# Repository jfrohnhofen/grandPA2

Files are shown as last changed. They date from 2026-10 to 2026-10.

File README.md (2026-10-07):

# grandPA2

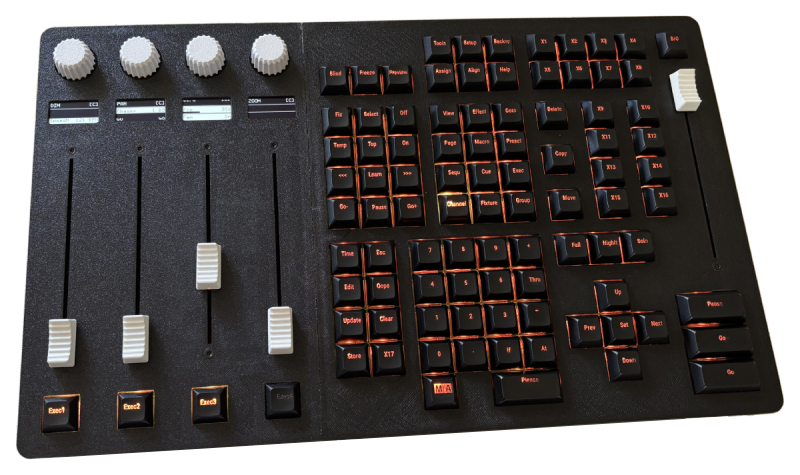
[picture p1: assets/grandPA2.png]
grandPA2 Hardware Controller


grandPA2 — the grandMA2 Physical Accessory — is a custom hardware controller inspired by the grandMA2 lighting console. It features a custom PCB, Rust-based STM32 firmware, and a companion Windows host application for grandMA2 WebRemote integration.

This is a private hobby project and is in no way affiliated with, endorsed by, or associated with MA Lighting Technology or the grandMA2 brand.

## Quick Start

To get the grandPA2 up and running, you need to build the firmware, configure your lighting software, and launch the host application:

1. **Flash Firmware:** Enter the firmware dev shell (`nix develop .#firmware`), build with `cargo build --release`, and flash to your Black Pill via `probe-rs` or `dfu-util`.
2. **Configure grandMA2 onPC:** Go to Global Settings and enable the **WebRemote**. Create a user account (default expected is username `grandPA2`, password `secret`).
3. **Launch Host App:** Enter the host dev shell (`nix develop .#host`), build with `cargo build --release --target x86_64-pc-windows-gnu`, and run the executable with your connection string: `grandPA2.exe grandPA2:secret@127.0.0.1:80`.

## Project Structure

- `firmware/` - Rust firmware for the STM32F4 (Black Pill) microcontroller.
- `host/` - Rust-based Windows companion application for screen scraping and two-way communication via grandMA2 WebRemote.
- `pcb/` - EasyEDA project and hardware design files.
- `keycaps/` - Python scripts to generate custom SVG legends for the keycaps.
- `casing/` - 3D models for the enclosure.

## Development Environment (Nix)

This project uses [Nix](https://nixos.org/) [Flakes](https://nixos.wiki/wiki/Flakes) to provide a reproducible development environment.

To enter the respective development environments with all necessary toolchains installed (Rust, cross-compilers, Python, Inkscape, etc.):

- **Firmware Dev Shell:** `nix develop .#firmware`
- **Windows Host App Dev Shell:** `nix develop .#host`
- **Keycap Generation Shell:** `nix develop .#keycaps`

---

## Hardware & PCB (`pcb/`)

The hardware is designed in EasyEDA. The `grandPA2.eprj` file can be imported into EasyEDA to view the schematics and PCB layout.

**Hardware Features:**
- STM32F411 (Black Pill) microcontroller
- 11x11 Switch Matrix (with 94 usable keys)
- 4x EC11 Rotary Encoders with push buttons
- 5x Analog Faders
- 4x OLED Displays (SH1106 via SPI)
- 94x WS2812 RGB LEDs

The button layout strictly follows the layout from a physical grandMA2 console, plus 16 extra buttons mapped as the X1 to X16 hardkeys. One fader acts as the Grand Master, while the other 4 faders are mapped as Executors 1-4. The buttons underneath the 4 faders are mapped as the main executor buttons for Executors 6-9.

The 4 rotary encoders are hardcoded to the following attributes:
- **Encoder 0:** Dimmer (Dim)
- **Encoder 1:** Position (Pan)
- **Encoder 2:** Position (Tilt)
- **Encoder 3:** Focus (Zoom)

The hardware is split into three separate boards for easier manufacturing and assembly:
1. **Main Board:** Hosts the Black Pill microcontroller and various IDC connectors to route signals.
2. **Matrix Board:** Contains the keyboard scanning matrix and the 94 RGB LEDs. It also contains a smaller sub-PCB for the executor buttons.
3. **Peripheral Boards:** Smaller boards, each used for connecting one display, one encoder, and one fader.

### MCU Pin Assignments
The Black Pill (STM32F411) uses the following pins for the various peripherals:

| Peripheral | Sub-component / Signal | Pin(s) |
| :--- | :--- | :--- |
| **Encoders** | Encoder 0 (A, B, Push) | `PA8`, `PA9`, `PC13` |
| | Encoder 1 (A, B, Push) | `PA15`, `PB3`, `PC14` |
| | Encoder 2 (A, B, Push) | `PB4`, `PB5`, `PB9` |
| | Encoder 3 (A, B, Push) | `PB6`, `PB7`, `PB8` |
| **Faders** | Faders 0 - 4 | `PA0`, `PA1`, `PA2`, `PA3`, `PA4` |
| **Matrix Scanner** | SCK, Row Latch, Row Data In | `PB13`, `PB12`, `PB14` |
| | Col Latch, Col Data Out | `PA10`, `PB15` |
| **Displays (SPI)** | SCK, MOSI, DC | `PA5`, `PA7`, `PC15` |
| | CS0, CS1, CS2, CS3 | `PB0`, `PB1`, `PB2`, `PB10` |
| **WS2812 LEDs** | Data Line | `PA6` |

### IDC Connector Pinouts (Main Board)
The main board routes signals to the peripherals via IDC connectors. The pinouts are as follows:

**Matrix (10-pin)**
| Odd Pin | Signal | Even Pin | Signal |
| :--- | :--- | :--- | :--- |
| **1** | `3V3` | **2** | `ROW_LATCH` |
| **3** | `SCK` | **4** | `ROW_DATA` |
| **5** | `COL_LATCH` | **6** | `COL_DATA` |
| **7** | `GND` | **8** | `GND` |
| **9** | `GND` | **10** | `GND` |

**Displays (10-pin)**
| Odd Pin | Signal | Even Pin | Signal |
| :--- | :--- | :--- | :--- |
| **1** | `CS` | **2** | `MOSI` |
| **3** | `3V3` | **4** | `DC` |
| **5** | `GND` | **6** | `RST` |
| **7** | `GND` | **8** | `SCK` |
| **9** | `GND` | **10** | `GND` |

**Encoders (6-pin)**
| Odd Pin | Signal | Even Pin | Signal |
| :--- | :--- | :--- | :--- |
| **1** | `ENC_A` | **2** | `ENC_BTN` |
| **3** | `ENC_B` | **4** | `GND` |
| **5** | `GND` | **6** | `GND` |

**Faders (6-pin)**
| Odd Pin | Signal | Even Pin | Signal |
| :--- | :--- | :--- | :--- |
| **1** | `3V3` | **2** | `FADER` |
| **3** | `GND` | **4** | `GND` |
| **5** | `GND` | **6** | `GND` |

**LEDs (6-pin)**
| Odd Pin | Signal | Even Pin | Signal |
| :--- | :--- | :--- | :--- |
| **1** | `5V` | **2** | `5V` |
| **3** | `LED_DATA` | **4** | `GND` |
| **5** | `GND` | **6** | `GND` |

### Bill of Materials (BOM)
In addition to the components listed in the PCB design, the following components are required:
- 1x STM32F411 Black Pill board
- 94x MX button switches
- 90x 1U keycaps
- 4x 2U keycaps
- 4x EC11 rotary encoders
- 5x linear faders (128mm travel, e.g., 10k linear)
- Various 6P, 10P, and 16P IDC sockets, connectors, and ribbon cables for inter-board connections.
- M3 8mm screws (for the casing).
- Self-cutting screws (for mounting the PCB).

### Keycaps & Legends (`keycaps/`)
Custom keycaps are required to mimic the lighting console layout. The `generate.py` script generates perfectly aligned, spaced SVGs for standard 1U and 2U keys, complete with a custom font and logos.
- To generate: `nix develop .#keycaps`, then `python generate.py`.
- The script uses Inkscape via the CLI to automatically convert the text elements into SVG paths, ensuring they render correctly for printing or laser engraving.

*Tip: For the best results, use transparent keycaps sprayed with matte black paint, and then laser-ablate the labels.*

### Casing (`casing/`)
The 3D printed casing for grandPA2 is designed in Onshape. You can view, copy, and export the CAD models from the following link:
[grandPA2 Casing on Onshape](https://cad.onshape.com/documents/a69522914b9fd6c3a378e748/w/ff3ce6cc18ab1158cfabc037/e/642326b3695c8e1d442461fe)
Exported STEP files are also in the repository. There is a "split" version that fits into the 256mm³ print volume of a Bambu Lab P1S printer.

---

## Firmware (`firmware/`)

The firmware is written in Rust for the STM32F411 (Black Pill) microcontroller. It acts as a USB MIDI Audio Class device.

### Protocol Details
The firmware and the host software communicate via standard USB MIDI, mixed with custom SysEx commands:

- **Hardware to Host (Standard MIDI):**
  - **Matrix Buttons:** Sent as MIDI Note On/Off messages (Notes 0–120) on Channel 1.
  - **Encoders:** The rotation is sent as Control Change (CC) messages (CC 0–3, relative 2's complement) on Channel 2. The encoder push buttons send Note On/Off messages (Notes 0–3) on Channel 2.
  - **Faders:** Sent as absolute Control Change (CC) messages (CC 0–4) on Channel 3.
  
- **Host to Hardware (Custom SysEx - ID 0x7D):**
  - **LED Updates (Command ID `0x10`):** Host sends 24-bit RGB colors for all 94 LEDs. The payload is 282 bytes (94 LEDs * 3 bytes for R, G, B). Each byte is 7-bit masked.
  - **OLED Displays (Command ID `0x20` to `0x2F`):** Host sends 1BPP pixel chunks. DisplayID is `(Cmd - 0x20) / 4` and ChunkID is `(Cmd - 0x20) % 4`. The payload is 7-bit packed and unpacked by the firmware into 256 bytes per chunk.

SysEx messages are wrapped in standard MIDI `0xF0` and `0xF7` bytes. The payload begins with the Custom Manufacturer ID `0x7D`, followed by the Command ID, and then the data payload bytes (which are strictly 7-bit compliant).

### Building and Flashing
1. Enter the firmware dev shell: `nix develop .#firmware`
2. Build the project: `cargo build --release`
3. Flash the firmware onto the Black Pill using `probe-rs` or `dfu-util`.

---

## Host Software (`host/`)

The host software is a Windows application written in Rust. It acts as the bridge between the grandPA2 hardware and the grandMA2 onPC software by combining screen scraping with WebRemote integration.

### grandMA2 WebRemote Integration

The host uses websockets to communicate with the grandMA2 WebRemote API. This handles bidirectional data transfer:
- **Fetching State:** Continuously requests `PresetTypesUpdate` and `PlaybacksUpdate` updates to render accurate encoder values and fader / button states onto the OLED displays.
- **Sending Commands:** Translates physical encoder turns and hardkey presses into WebRemote JSON commands (e.g., `PresetType`, `HardKey`, `Encoder`).

### Screen Scraping for LED Feedback

Because grandMA2 onPC doesn't expose a native API to read the LED state of the on-screen buttons, the host software falls back to screen scraping. 

It uses Windows Graphics Capture (DXGI) and Direct3D11 to capture frames from the grandMA2 onPC window in real-time. It checks the colors of specific pixels at normalized coordinates mapped to the grandMA2 UI to determine if a button is active/lit. These active states are translated into the custom SysEx protocol and sent to the microcontroller, lighting up the physical WS2812 RGB LEDs.

### Building
The Nix environment provides a MinGW-w64 cross-compiler if you are building from Linux.
1. Enter the host dev shell: `nix develop .#host`
2. Build the project: `cargo build --release --target x86_64-pc-windows-gnu`

If you are on Windows natively, you can build using the MSVC toolchain with standard `cargo build --release`.

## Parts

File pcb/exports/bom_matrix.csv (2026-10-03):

No. | Quantity | Comment | Designator | Footprint | Value | Manufacturer Part | Manufacturer | Supplier Part | Supplier
1 | 11 | 10uF | C1,C2,C3,C4,C5,C6,C7,C8,C9,C10,C11 | C0805 | 10uF | CL21A106KAYNNNE | SAMSUNG(三星) | C15850 | LCSC
2 | 4 | 100nF | C15,C16,C17,C18 | C0402 | 100nF | CL05B104KO5NNNC | SAMSUNG(三星) | C1525 | LCSC
3 | 94 | 1N4148WS | D1,D2,D3,D4,D5,D63,D64,D65,D66,D67,D68,D69,D70,D71,D72,D73,D74,D75,D76,D78,D80,D82,D83,D84,D85,D86,D87,D88,D89,D90,D91,D92,D93,D94,D95,D96,D97,D98,D99,D100,D101,D102,D103,D104,D105,D106,D107,D108,D109,D110,D111,D112,D113,D114,D115,D116,D117,D118,D119,D120,D121,D122,D123,D124,D125,D126,D127,D128,D129,D130,D131,D132,D133,D134,D135,D136,D137,D138,D139,D141,D142,D143,D144,D145,D146,D147,D148,D149,D150,D151,D152,D153,D154,D155 | SOD-323_L1.8-W1.3-LS2.5-RD |  | 1N4148WS | CJ(江苏长电/长晶) | C2128 | LCSC
4 | 1 | 1812L150/24MR | F1 | F1812 |  | 1812L150/24MR | Littelfuse(美国力特) | C142805 | LCSC
5 | 94 | WS2812B-2020-V6 | LED1,LED2,LED3,LED4,LED5,LED63,LED64,LED65,LED66,LED67,LED68,LED69,LED70,LED71,LED72,LED73,LED74,LED75,LED76,LED78,LED80,LED82,LED83,LED84,LED85,LED86,LED87,LED88,LED89,LED90,LED91,LED92,LED93,LED94,LED95,LED96,LED97,LED98,LED99,LED100,LED101,LED102,LED103,LED104,LED105,LED106,LED107,LED108,LED109,LED110,LED111,LED112,LED113,LED114,LED115,LED116,LED117,LED118,LED119,LED120,LED121,LED122,LED123,LED124,LED125,LED126,LED127,LED128,LED129,LED130,LED131,LED132,LED133,LED134,LED135,LED136,LED137,LED138,LED139,LED141,LED142,LED143,LED144,LED145,LED146,LED147,LED148,LED149,LED150,LED151,LED152,LED153,LED154,LED155 | LED-SMD_4P-L2.2-W2.0-P1.00_WS2815C-2020-4P |  | WS2812B-2020-V6 | worldsemi | C52917434 | LCSC
6 | 1 | 2.54-2*8P简牛 | P1 | IDC-TH_16P-P2.54_C3406 |  | 2.54-2*8P简牛 | BOOMELE(博穆精密) | C3406 | LCSC
7 | 2 | 2.54-2*5P简牛 | P2,P3 | IDC-TH_10P-P2.54_C5665 |  | 2.54-2*5P简牛 | BOOMELE(博穆精密) | C5665 | LCSC
8 | 11 | 10kΩ | R1,R2,R3,R4,R5,R6,R7,R8,R9,R10,R11 | R0402 | 10kΩ | 0402WGF1002TCE | UNI-ROYAL(厚声) | C25744 | LCSC
9 | 94 | MX1A-11NW | SW1,SW2,SW3,SW4,SW5,SW63,SW64,SW65,SW66,SW67,SW68,SW69,SW70,SW71,SW72,SW73,SW74,SW75,SW76,SW78,SW80,SW82,SW83,SW84,SW85,SW86,SW87,SW88,SW89,SW90,SW91,SW92,SW93,SW94,SW95,SW96,SW97,SW98,SW99,SW100,SW101,SW102,SW103,SW104,SW105,SW106,SW107,SW108,SW109,SW110,SW111,SW112,SW113,SW114,SW115,SW116,SW117,SW118,SW119,SW120,SW121,SW122,SW123,SW124,SW125,SW126,SW127,SW128,SW129,SW130,SW131,SW132,SW133,SW134,SW135,SW136,SW137,SW138,SW139,SW141,SW142,SW143,SW144,SW145,SW146,SW147,SW148,SW149,SW150,SW151,SW152,SW153,SW154,SW155 | SW-TH_MX1A-11NW |  | MX1A-11NW | CHERRY | C3316924 | LCSC
10 | 2 | 74HC595D,118 | U1,U2 | SOIC-16_L9.9-W3.9-P1.27-LS6.0-BL |  | 74HC595D,118 | Nexperia(安世) | C5947 | LCSC
11 | 2 | 74HC165D,653 | U3,U4 | SOIC-16_L9.9-W3.9-P1.27-LS6.0-BL |  | 74HC165D,653 | Nexperia(安世) | C5613 | LCSC

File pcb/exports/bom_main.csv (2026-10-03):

No. | Quantity | Comment | Designator | Footprint | Value | Manufacturer Part | Manufacturer | Supplier Part | Supplier
1 | 8 | 10nF | C3,C6,C21,C23,C27,C29,C30,C32 | C0402 | 10nF | CL05B103KB5NNNC | SAMSUNG(三星) | C15195 | LCSC
2 | 9 | 100nF | C5,C7,C17,C18,C19,C20,C22,C28,C31 | C0402 | 100nF | CL05B104KO5NNNC | SAMSUNG(三星) | C1525 | LCSC
3 | 5 | 2.54-2*5P简牛 | P6,P21,P22,P23,P24 | IDC-TH_10P-P2.54_C5665 |  | 2.54-2*5P简牛 | BOOMELE(博穆精密) | C5665 | LCSC
4 | 10 | 2.54-2*3P简牛 | P7,P12,P13,P18,P19,P20,P25,P26,P27,P28 | IDC-TH_6P-P2.54_C11214 |  | 2.54-2*3P简牛 | BOOMELE(博穆精密) | C11214 | LCSC
5 | 1 | 470Ω | R1 | R0402 | 470Ω | 0402WGF4700TCE | UNI-ROYAL(厚声) | C25117 | LCSC
6 | 9 | 1kΩ | R5,R12,R31,R32,R33,R34,R37,R49,R55 | R0402 | 1kΩ | 0402WGF1001TCE | UNI-ROYAL(厚声) | C11702 | LCSC
7 | 20 | 10kΩ | R6,R7,R9,R10,R11,R35,R36,R38,R39,R40,R47,R48,R50,R51,R52,R53,R54,R56,R57,R58 | R0402 | 10kΩ | 0402WGF1002TCE | UNI-ROYAL(厚声) | C25744 | LCSC
8 | 1 | BlackPill | U1 | Z_module_black_pill_STM32F411

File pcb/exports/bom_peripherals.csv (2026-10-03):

No. | Quantity | Comment | Designator | Footprint | Value | Manufacturer Part | Manufacturer | Supplier Part | Supplier
1 | 1 | HDR-M_2.54_1x5P | H1 | HDR-TH_5P-P2.54-V-M
2 | 1 | HS13L02W4S01 | OLED1 | OLED-TH_HS13L02W4S01 |  | HS13L02W4S01 | HS(汉昇) | C42432558 | LCSC
3 | 1 | 2.54-2*8P简牛 | P1 | IDC-TH_16P-P2.54_C3406 |  | 2.54-2*8P简牛 | BOOMELE(博穆精密) | C3406 | LCSC
4 | 1 | EC11E15244B2 | SW2 | SW-TH_EC11XXXXXXXX

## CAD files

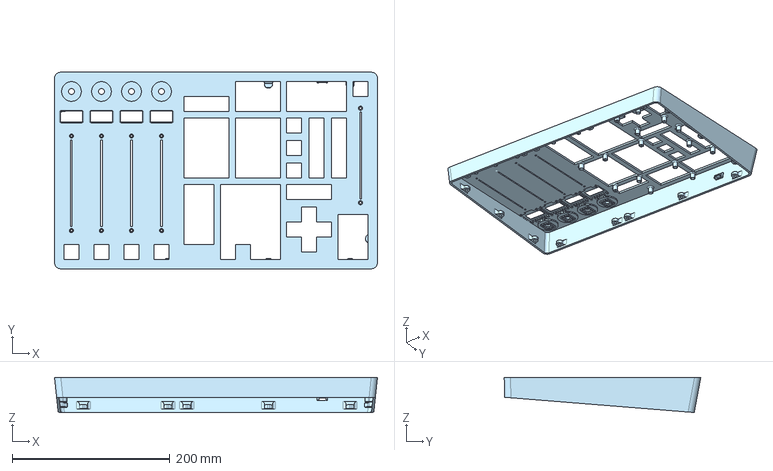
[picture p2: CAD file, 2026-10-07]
casing/casing_top.step
409.9 x 249.5 x 44.5 mm

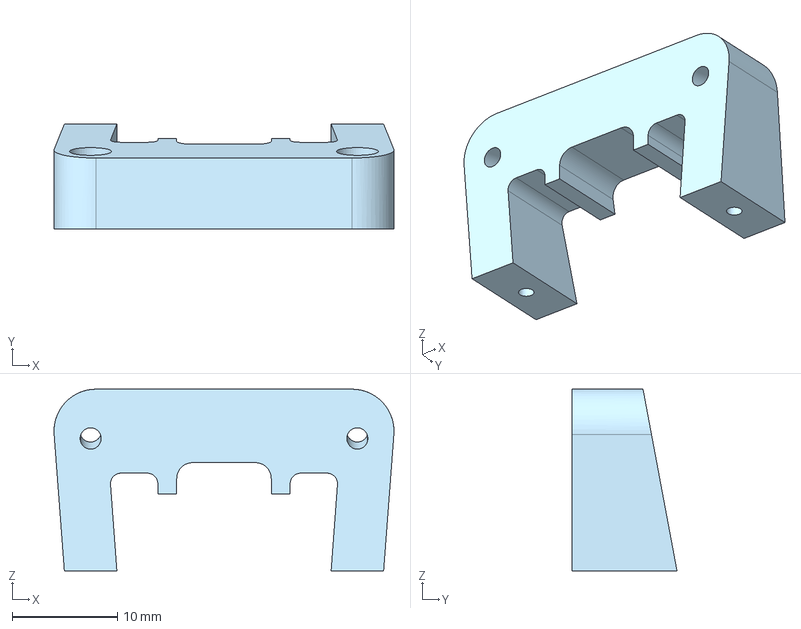
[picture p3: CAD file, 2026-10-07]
casing/pcb_mount.step
32.4 x 10.0 x 17.3 mm

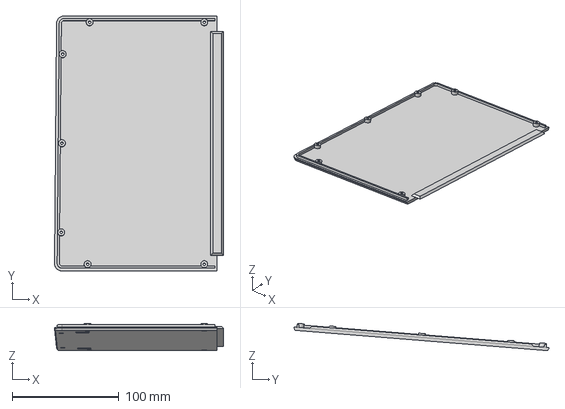
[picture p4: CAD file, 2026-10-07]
casing/casing_bottom-left.step
158.2 x 238.7 x 25.6 mm

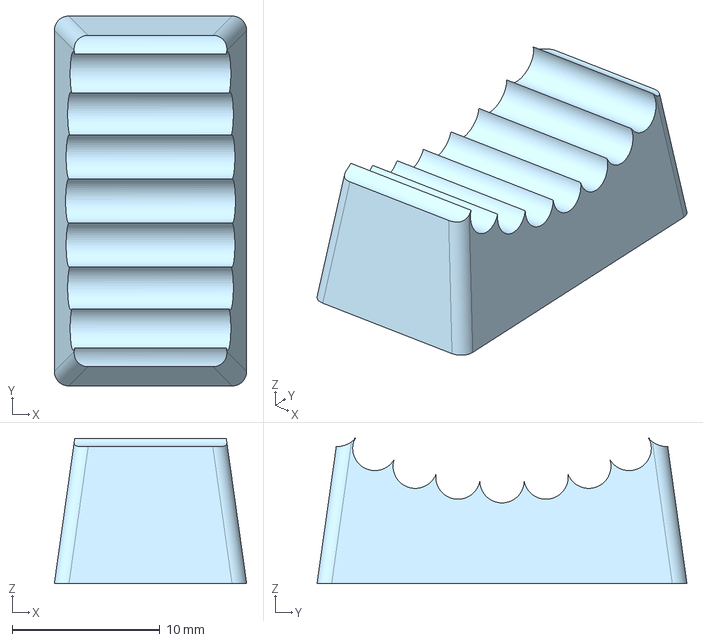
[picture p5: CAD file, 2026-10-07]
casing/fader_cap.step
13.0 x 25.0 x 9.81 mm

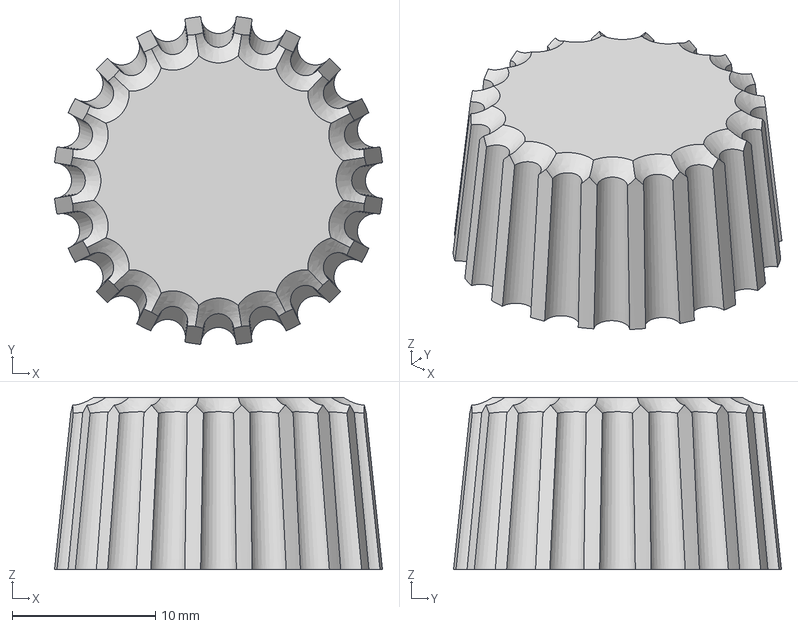
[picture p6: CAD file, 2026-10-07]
casing/encoder_knob.step
22.9 x 22.9 x 12.0 mm

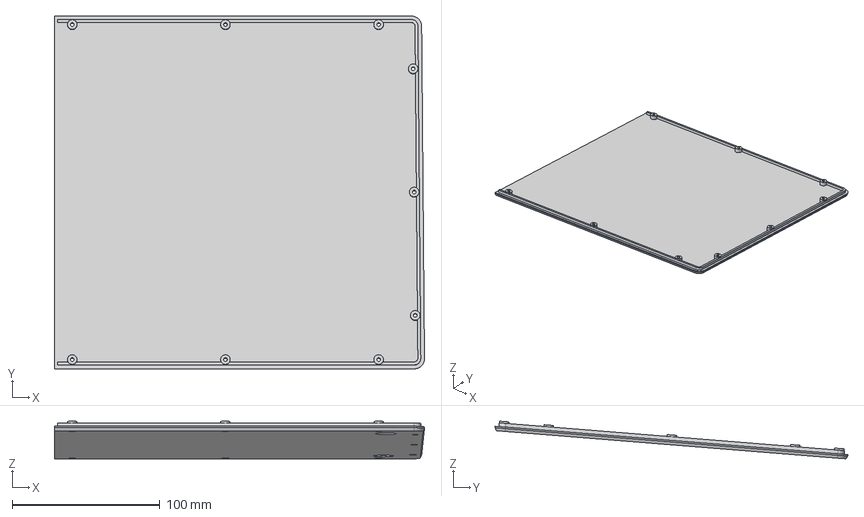
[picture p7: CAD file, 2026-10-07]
casing/casing_bottom-right.step
250.3 x 238.7 x 25.6 mm

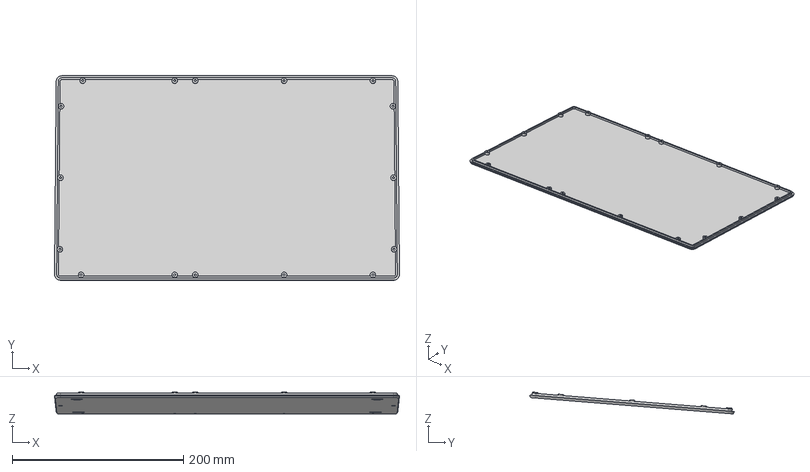
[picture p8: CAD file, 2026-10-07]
casing/casing_bottom.step
402.5 x 238.7 x 25.6 mm

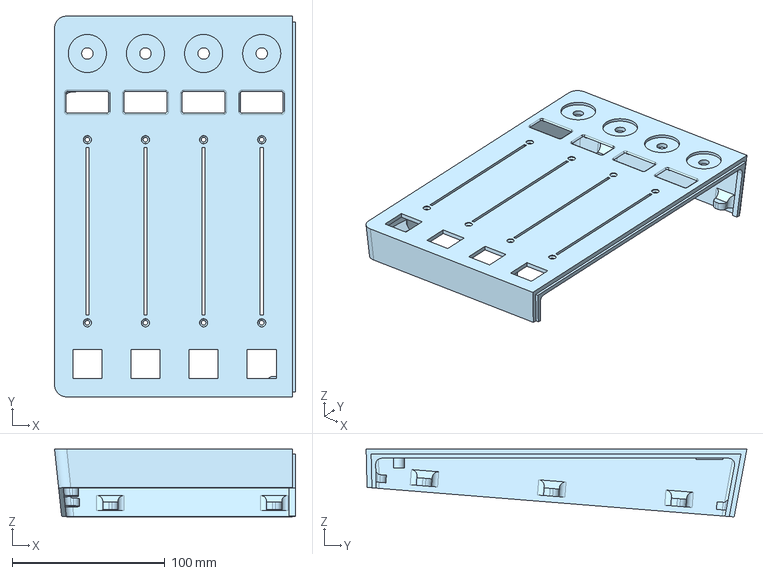
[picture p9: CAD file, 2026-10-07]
casing/casing_top-left.step
157.9 x 249.5 x 44.5 mm

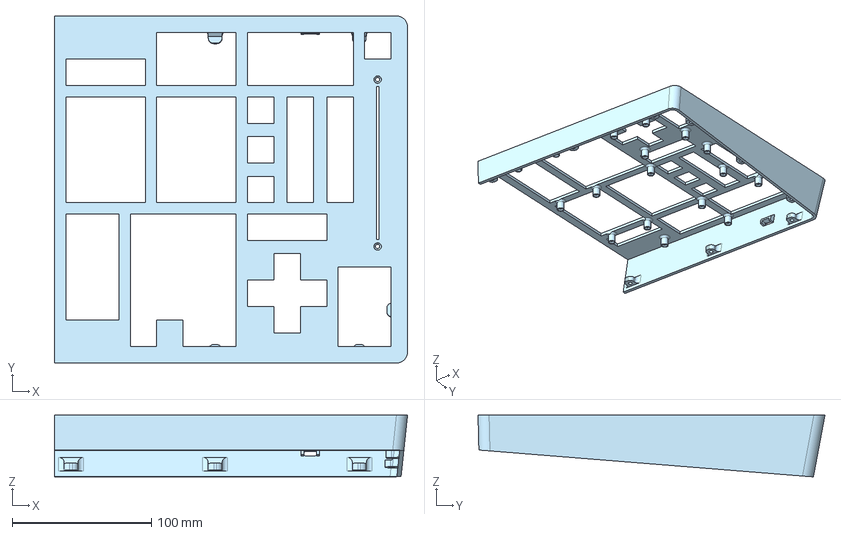
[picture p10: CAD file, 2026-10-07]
casing/casing_top-right.step
254.0 x 249.5 x 44.5 mm

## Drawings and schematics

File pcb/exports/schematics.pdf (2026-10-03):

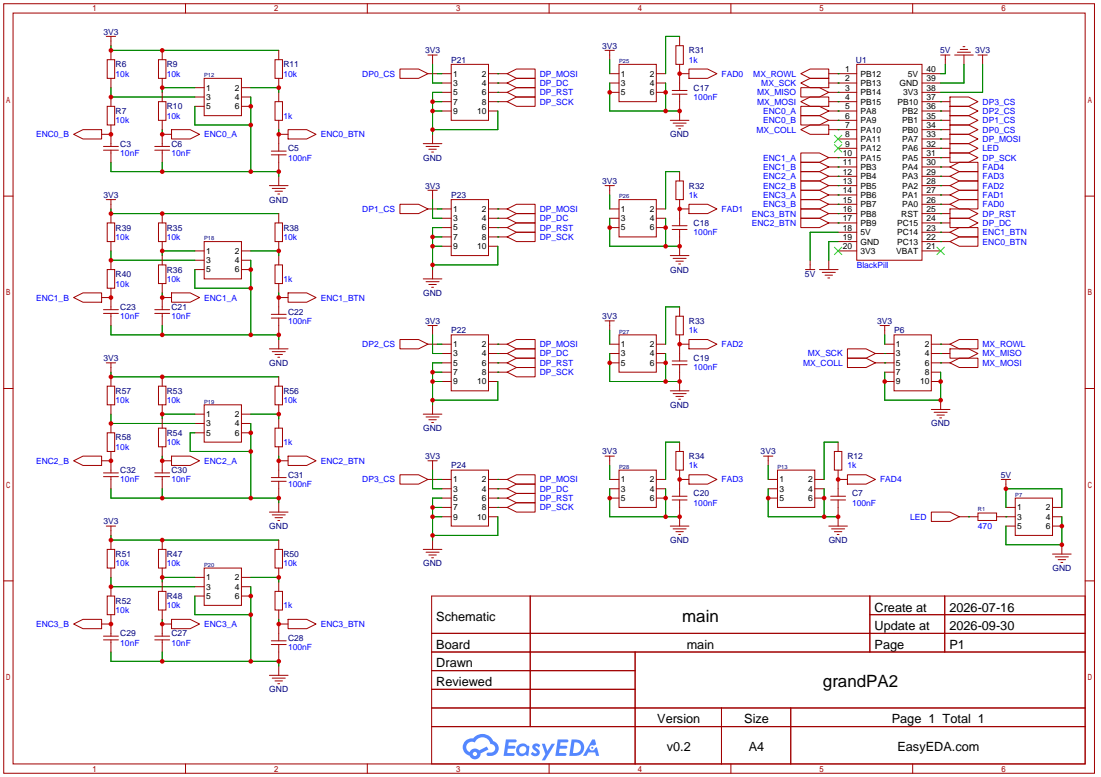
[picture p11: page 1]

Schematic | main | Create at | 2026-07-16

Update at | 2026-09-30

Board | main | Page | P1
Drawn | | grandPA2
Reviewed

v0.2 | A4 | EasyEDA.comROW

# DS 10 D0 11 D1 12 D2 13 D3 14 CE# 15 VCC 16

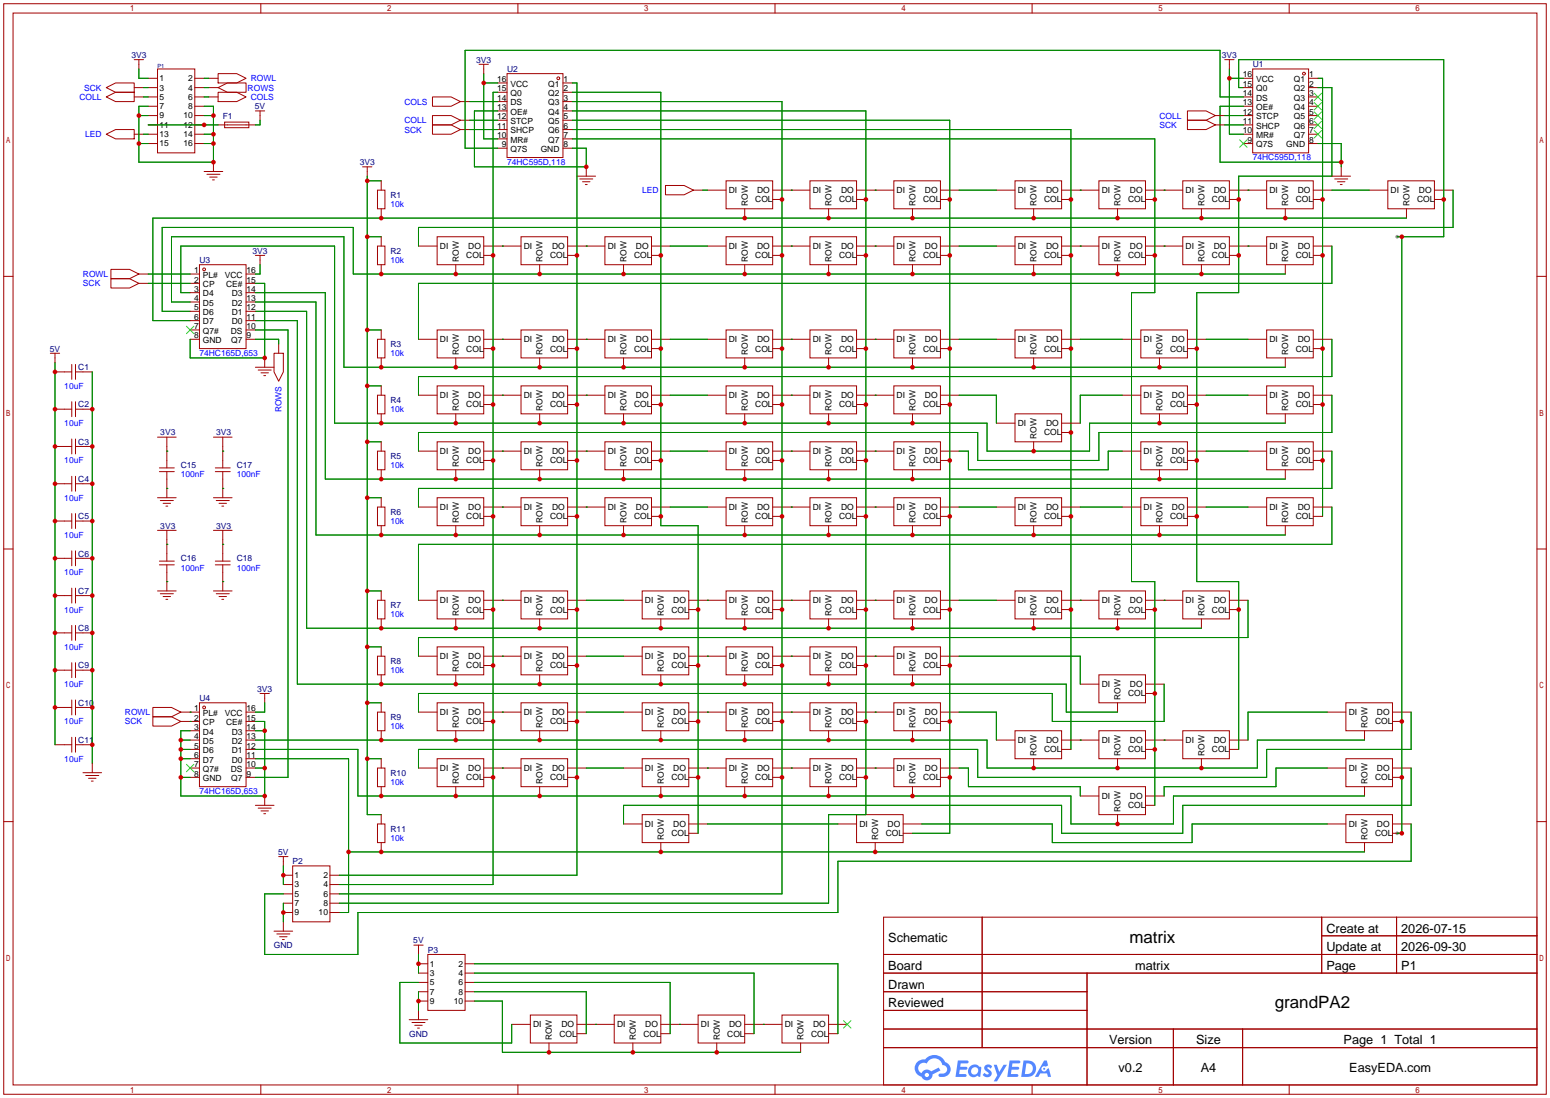
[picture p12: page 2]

MR# 10 SHCP 11 STCP 12 OE# 13 DS 14 Q0 15 VCC 16

COL | DI DO COL | DI DO COL | DI DO COL | DI DO COL | DI DO COL | DI DO COL

Board | matrix | Page | P1
Drawn | | grandPA2
Reviewed

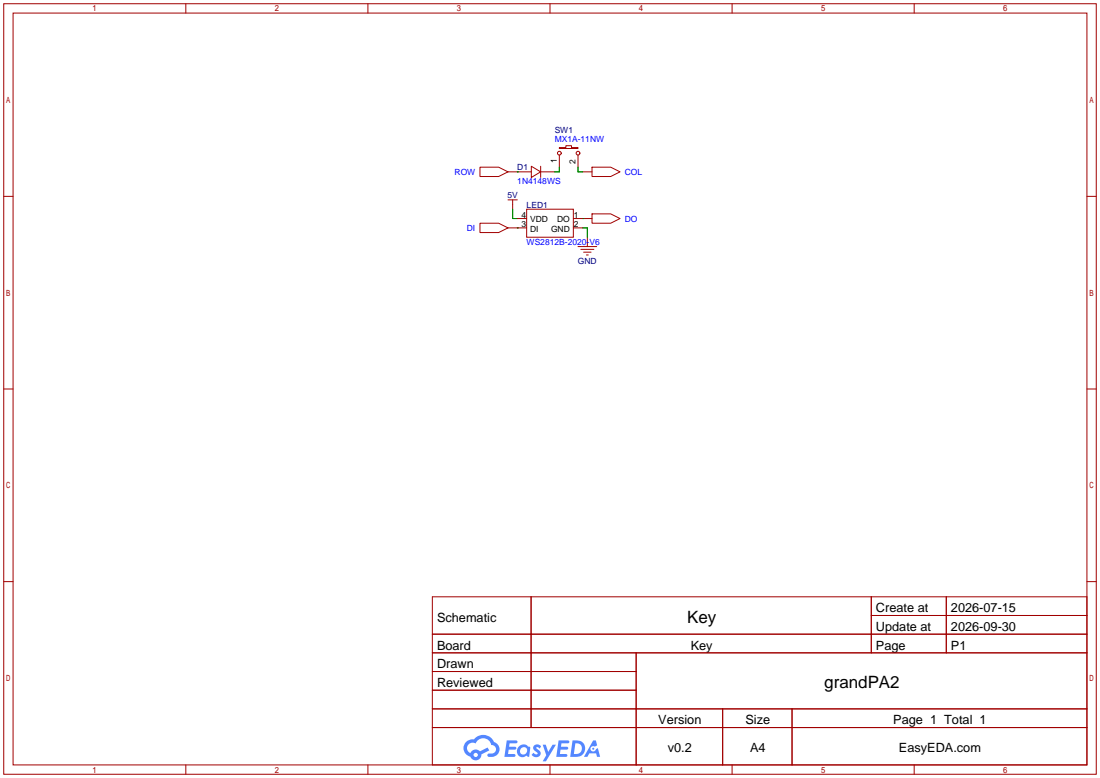
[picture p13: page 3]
EasyEDA.com; GND; ROW; COL; DO 1 GND 2; VDD 4; LED1

Schematic | Key | Create at | 2026-07-15

Update at | 2026-09-30

Board | Key | Page | P1
Drawn | | grandPA2
Reviewed

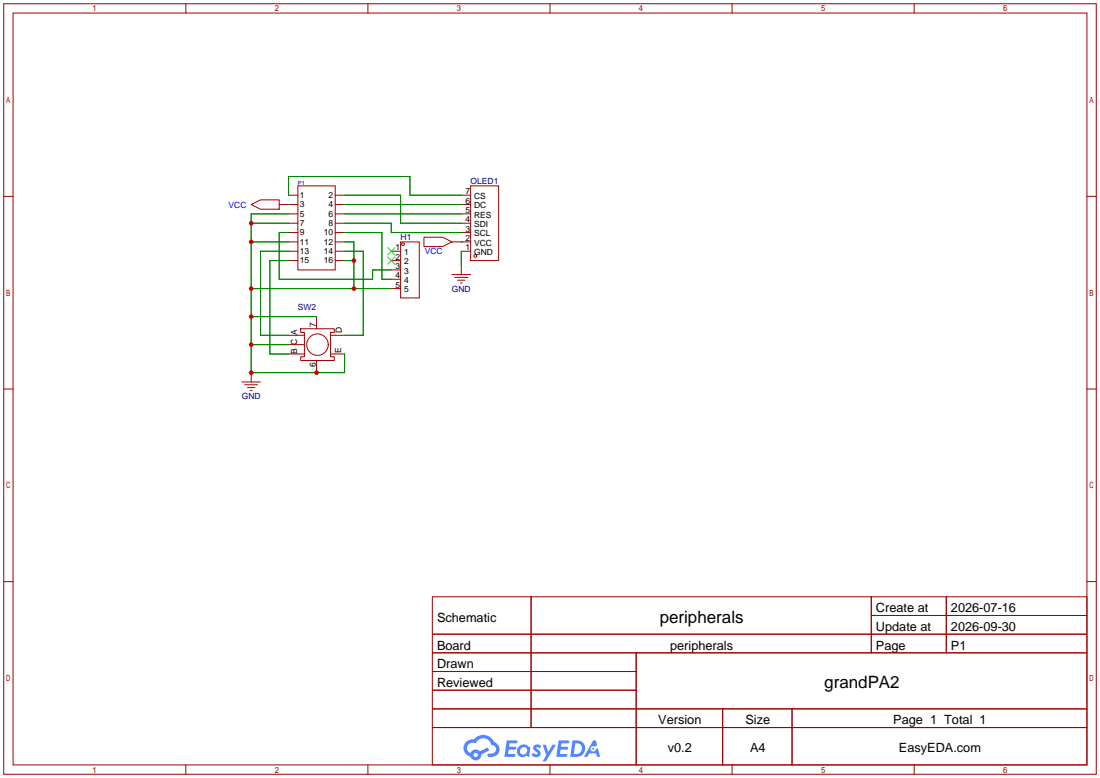
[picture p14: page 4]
EasyEDA.com; GND 1; VCC 2; SCL 3; SDI 4; RES 5; OLED1; VCC; GND

Schematic | peripherals | Create at | 2026-07-16

Update at | 2026-09-30

Board | peripherals | Page | P1
Drawn | | grandPA2
Reviewed

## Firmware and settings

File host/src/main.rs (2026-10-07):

mod display_renderer;
mod grandma2_client;
mod keymap;
mod midi_manager;
mod screen_capture;
use display_renderer::DisplayState;
use grandma2_client::{ButtonFunction, ExecUpdate, GrandMA2Client, GrandMA2Command, GrandMA2Event};
use keymap::{KeyFunction, MASTER_KEY_MAP};
use midi_manager::{HardwareInputEvent, MidiManager};
use std::error::Error;
use std::sync::{Arc, Mutex};
use tokio::sync::mpsc;

fn get_encoder_context(encoder_id: usize, state: &DisplayState) -> Option<(&'static str, &'static str, bool, bool)> {
    let fine = state.columns[encoder_id].encoder.fine_mode;
    let is_active = state.columns[encoder_id].encoder.group_active;
    match encoder_id {
        0 => Some(("Dimmer", "Dim", fine, is_active)),
        1 => Some(("Position", "Pan", fine, is_active)),
        2 => Some(("Position", "Tilt", fine, is_active)),
        3 => Some(("Focus", "Zoom", fine, is_active)),
        _ => None,
    }
}

async fn activate_preset_if_needed(preset_type: &str, is_active: bool, grandma2: &mpsc::Sender<GrandMA2Command>) {
    if !is_active {
        let _ = grandma2.send(GrandMA2Command::Command { cmd: format!("PresetType \"{}\"", preset_type) }).await;
    }
}

#[tokio::main]
async fn main() -> Result<(), Box<dyn Error>> {
    println!("=== grandPA2 Host Application ===");

    // Channels for hardware input and grandMA2 network events
    let (input_tx, mut input_rx) = mpsc::channel::<HardwareInputEvent>(1000);
    let (grandma2_tx, mut grandma2_rx) = mpsc::channel::<GrandMA2Event>(1000);
    let (led_tx, mut led_rx) = mpsc::channel::<Vec<(usize, bool)>>(1000);

    // The single source of truth for the physical displays
    let display_state = Arc::new(Mutex::new(DisplayState::new()));

    let grandma2 = GrandMA2Client::start(grandma2_tx.clone());
    let midi_handle = MidiManager::start(input_tx);

    // Screen capture driver
    screen_capture::windows_capture::start(led_tx);

    // Render driver
    let display_state_for_render = Arc::clone(&display_state);
    let midi_handle_for_render = Arc::clone(&midi_handle);
    crate::display_renderer::start(display_state_for_render, midi_handle_for_render);

    let mut last_encoder_press: [Option<std::time::Instant>; 4] = [None; 4];

    loop {
        tokio::select! {
            Some(evt) = input_rx.recv() => {
                match evt {
                    HardwareInputEvent::DeviceConnected => {
                        display_state.lock().unwrap().force_redraw = true;
                    }
                    HardwareInputEvent::Button { button_id, pressed } => {
                        let key = &MASTER_KEY_MAP[button_id];
                        match key.function {
                            KeyFunction::HardKey(code) => {
                                let _ = grandma2.send(GrandMA2Command::HardKey { code, pressed }).await;
                            }
                            KeyFunction::ExecButton(exec_num) => {
                                if exec_num >= 6 && exec_num <= 9 {
                                        let disp_idx = (exec_num - 6) as usize;
                                        let mut state = display_state.lock().unwrap();
                                        state.columns[disp_idx].button.is_pressed = pressed;
                                        state.columns[disp_idx].button.flash_time = Some(std::time::Instant::now());
                                }
                                let _ = grandma2.send(GrandMA2Command::ExecButton { exec_num, pressed }).await;
                            }
                        }
                    }
                    HardwareInputEvent::EncoderTurn { encoder_id, delta } => {
                        let context = {
                            let state = display_state.lock().unwrap();
                            get_encoder_context(encoder_id, &state)
                        };

                        if let Some((preset_type, attr, fine, is_active)) = context {
                            activate_preset_if_needed(preset_type, is_active, &grandma2).await;
                            let _ = grandma2.send(GrandMA2Command::Encoder {
                                attribute: attr.to_string(),
                                delta,
                                fine,
                            }).await;
                        }
                    }
                    HardwareInputEvent::EncoderButton { encoder_id, pressed } => {
                        if pressed {
                            let now = std::time::Instant::now();
                            let is_double_tap = if let Some(last) = last_encoder_press[encoder_id] {
                                now.duration_since(last).as_millis() < 300
                            } else {
                                false
                            };
                            last_encoder_press[encoder_id] = Some(now);
                            let context = {
                                let mut state = display_state.lock().unwrap();
                                state.columns[encoder_id].encoder.fine_mode = !state.columns[encoder_id].encoder.fine_mode;
                                get_encoder_context(encoder_id, &state)
                            };

                            if let Some((preset_type, attr, _, is_active)) = context {
                                if is_double_tap {
                                    let _ = grandma2.send(GrandMA2Command::Command {
                                        cmd: format!("Off Attribute \"{}\"", attr)
                                    }).await;
                                    last_encoder_press[encoder_id] = None;
                                } else {
                                    activate_preset_if_needed(preset_type, is_active, &grandma2).await;
                                }
                            }
                        }
                    }
                    HardwareInputEvent::FaderMove { fader_id, level } => {
                        if fader_id < 4 {
                            {
                                let mut state = display_state.lock().unwrap();
                                state.columns[fader_id].fader.value = level;
                            }
                            let _ = grandma2.send(GrandMA2Command::ExecFader {
                                exec_num: (fader_id + 1) as u8,
                                level,
                            }).await;
                        } else {
                            let _ = grandma2.send(GrandMA2Command::GrandMaster { level }).await;
                        }
                    }
                }
            }

            Some(evt) = grandma2_rx.recv() => {
                match evt {
                    GrandMA2Event::PresetTypesUpdate(encoders) => {
                        let mut state = display_state.lock().unwrap();
                        for (i, enc) in encoders.into_iter().enumerate() {
                            state.columns[i].encoder = crate::display_renderer::EncoderState {
                                value: enc.value,
                                active: enc.active,
                                programmer: enc.programmer,
                                group_active: enc.group_active,
                                fine_mode: state.columns[i].encoder.fine_mode,
                            };
                        }
                    }
                    GrandMA2Event::PlaybacksUpdate(updates) => {
                        let mut state = display_state.lock().unwrap();
                        for update in updates {
                            match update {
                                ExecUpdate::Fader(idx, fader_exec) => {
                                    if idx < 4 {
                                        state.columns[idx].fader.exec = fader_exec;
                                    }
                                }
                                ExecUpdate::Button(idx, button_exec) => {
                                    if idx >= 5 && idx <= 8 {
                                        let slot_idx = idx - 5;
                                        let led_idx = 90 + slot_idx;
                                        state.leds[led_idx] = match button_exec.function {
                                            ButtonFunction::Empty => crate::display_renderer::LedState::Off,
                                            ButtonFunction::Toggle if button_exec.active => crate::display_renderer::LedState::Active,
                                            ButtonFunction::Toggle => crate::display_renderer::LedState::Inactive,
                                            _ => crate::display_renderer::LedState::Active,
                                        };
                                        state.columns[slot_idx].button.exec = button_exec;
                                    }
                                }
                            }
                        }
                    }
                }
            }

            Some(updates) = led_rx.recv() => {
                let mut state = display_state.lock().unwrap();
                for (idx, is_active) in updates {
                    state.leds[idx] = if is_active {
                        crate::display_renderer::LedState::Active
                    } else {
                        crate::display_renderer::LedState::Inactive
                    };
                }
            }
        }
    }
}

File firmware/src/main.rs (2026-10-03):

#![no_std]
#![no_main]

use cortex_m_rt::entry;
use panic_halt as _;

use stm32f4xx_hal::{
    adc::{config::AdcConfig, Adc},
    gpio::{
        alt::otg_fs::{Dm, Dp},
        Output, PushPull, PA6,
    },
    otg_fs::{UsbBus, USB},
    pac,
    prelude::*,
    qei::Qei,
};

use usb_device::prelude::*;
use usbd_midi::UsbMidiClass;

use grandpa2_firmware::{
    displays::DisplaySystem, encoders::EncoderSystem, faders::FaderSystem, leds::LedSystem, matrix::MatrixScanner,
    protocol::HostCommand, usb_midi::UsbMidiManager,
};

#[entry]
fn main() -> ! {
    let dp = pac::Peripherals::take().unwrap();

    let rcc = dp.RCC.constrain();
    let clocks = rcc.cfgr.sysclk(48.MHz()).require_pll48clk().freeze();

    // Give external components (OLEDs, WS2812s) time to power up before sending init commands.
    // At 48MHz, 12,000,000 cycles is roughly 250ms.
    cortex_m::asm::delay(12_000_000);

    let gpioa = dp.GPIOA.split();
    let gpiob = dp.GPIOB.split();
    let gpioc = dp.GPIOC.split();

    // 1. USB MIDI Setup
    let usb_dm = gpioa.pa11.into_alternate();
    let usb_dp = gpioa.pa12.into_alternate();

    let usb = USB {
        usb_global: dp.OTG_FS_GLOBAL,
        usb_device: dp.OTG_FS_DEVICE,
        usb_pwrclk: dp.OTG_FS_PWRCLK,
        pin_dm: Dm::PA11(usb_dm),
        pin_dp: Dp::PA12(usb_dp),
        hclk: clocks.hclk(),
    };

    static mut EP_MEMORY: [u32; 1024] = [0; 1024];
    #[allow(static_mut_refs)]
    let usb_bus = UsbBus::new(usb, unsafe { &mut EP_MEMORY });

    let midi_class = UsbMidiClass::new(&usb_bus, 1, 1).unwrap();
    let usb_dev = UsbDeviceBuilder::new(&usb_bus, UsbVidPid(0x1209, 0x0001))
        .strings(&[StringDescriptors::default().manufacturer("grandPA2").product("grandPA2").serial_number("000001")])
        .unwrap()
        .device_class(0x01) // USB_CLASS_AUDIO
        .build();

    let mut usb_midi = UsbMidiManager::new(usb_dev, midi_class);

    // 2. Rotary Encoders Setup
    let enc0_a = gpioa.pa8.into_alternate();
    let enc0_b = gpioa.pa9.into_alternate();
    let qei0 = Qei::new(dp.TIM1, (enc0_a, enc0_b));

    let enc1_a = gpioa.pa15.into_alternate();
    let enc1_b = gpiob.pb3.into_alternate();
    let qei1 = Qei::new(dp.TIM2, (enc1_a, enc1_b));

    let enc2_a = gpiob.pb4.into_alternate();
    let enc2_b = gpiob.pb5.into_alternate();
    let qei2 = Qei::new(dp.TIM3, (enc2_a, enc2_b));

    let enc3_a = gpiob.pb6.into_alternate();
    let enc3_b = gpiob.pb7.into_alternate();
    let qei3 = Qei::new(dp.TIM4, (enc3_a, enc3_b));

    let enc_btn0 = gpioc.pc13.into_floating_input();
    let enc_btn1 = gpioc.pc14.into_floating_input();
    let enc_btn2 = gpiob.pb9.into_floating_input();
    let enc_btn3 = gpiob.pb8.into_floating_input();

    let mut encoders = EncoderSystem::new(qei0, qei1, qei2, qei3, enc_btn0, enc_btn1, enc_btn2, enc_btn3);

    // 3. Faders ADC Setup
    let fader0 = gpioa.pa0.into_analog();
    let fader1 = gpioa.pa1.into_analog();
    let fader2 = gpioa.pa2.into_analog();
    let fader3 = gpioa.pa3.into_analog();
    let fader4 = gpioa.pa4.into_analog();
    let adc = Adc::adc1(dp.ADC1, true, AdcConfig::default());

    let mut faders = FaderSystem::new(adc, fader0, fader1, fader2, fader3, fader4);

    // 4. Matrix Scanner Setup
    let sck = gpiob.pb13.into_push_pull_output();
    let row_latch = gpiob.pb12.into_push_pull_output();
    let row_data = gpiob.pb14.into_floating_input();
    let col_latch = gpioa.pa10.into_push_pull_output();
    let col_data = gpiob.pb15.into_push_pull_output();

    let mut matrix = MatrixScanner::new(sck, row_latch, row_data, col_latch, col_data);

    // 5. Displays Setup
    let dc = gpioc.pc15.into_push_pull_output();
    let cs0 = gpiob.pb0.into_push_pull_output();
    let cs1 = gpiob.pb1.into_push_pull_output();
    let cs2 = gpiob.pb2.into_push_pull_output();
    let cs3 = gpiob.pb10.into_push_pull_output();

    let mut displays = DisplaySystem::new(dp.SPI1, gpioa.pa5, gpioa.pa7, dc, cs0, cs1, cs2, cs3, &clocks);

    // 6. WS2812 RGB LEDs Setup
    let led_pin: PA6<Output<PushPull>> = gpioa.pa6.into_push_pull_output();
    let mut leds = LedSystem::new(led_pin);

    loop {
        // A. Poll USB MIDI for incoming commands from grandMA2
        usb_midi.poll(|cmd| match cmd {
            HostCommand::SetAllRgbLeds { colors } => {
                leds.set_all_rgb_7bit(&colors);
            }
            HostCommand::SetDisplayPixelChunk { display_id, chunk_id, pixels } => {
                displays.set_pixel_chunk(display_id, chunk_id, &pixels);
            }
        });

        // B. Scan 11x11 Matrix -> Send MIDI Note events to PC
        matrix.scan(|event| {
            usb_midi.send_event(event);
        });

        // C. Poll Encoders & Buttons -> Send MIDI CC / Note events to PC
        encoders.poll(|event| {
            usb_midi.send_event(event);
        });

        // D. Poll Analog Faders -> Send MIDI CC events to PC
        faders.poll(|event| {
            usb_midi.send_event(event);
        });

        // E. Flush Display & LED updates
        displays.update();
        leds.update();
    }
}

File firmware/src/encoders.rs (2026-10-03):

//! 4 Quadrature Rotary Encoders & Push Buttons Module

use crate::protocol::BoardEvent;
use core::ops::FnMut;
use embedded_hal::Qei;
use stm32f4xx_hal::{
    gpio::{Input, PB8, PB9, PC13, PC14},
    pac::{TIM1, TIM2, TIM3, TIM4},
    qei::Qei as Stm32Qei,
};

pub struct EncoderSystem {
    qei0: Stm32Qei<TIM1>,
    qei1: Stm32Qei<TIM2>,
    qei2: Stm32Qei<TIM3>,
    qei3: Stm32Qei<TIM4>,

    btn0: PC13<Input>,
    btn1: PC14<Input>,
    btn2: PB9<Input>,
    btn3: PB8<Input>,

    last_counts: [u16; 4],
    last_btns: [bool; 4],
}

impl EncoderSystem {
    pub fn new(
        qei0: Stm32Qei<TIM1>,
        qei1: Stm32Qei<TIM2>,
        qei2: Stm32Qei<TIM3>,
        qei3: Stm32Qei<TIM4>,
        btn0: PC13<Input>,
        btn1: PC14<Input>,
        btn2: PB9<Input>,
        btn3: PB8<Input>,
    ) -> Self {
        let initial_counts = [qei0.count(), qei1.count() as u16, qei2.count(), qei3.count()];
        let initial_btns = [btn0.is_low(), btn1.is_low(), btn2.is_low(), btn3.is_low()];

        Self { qei0, qei1, qei2, qei3, btn0, btn1, btn2, btn3, last_counts: initial_counts, last_btns: initial_btns }
    }

    /// Read encoders and buttons, firing events for turns and button presses
    pub fn poll<F>(&mut self, mut on_event: F)
    where
        F: FnMut(BoardEvent),
    {
        let current_counts = [self.qei0.count(), self.qei1.count() as u16, self.qei2.count(), self.qei3.count()];

        let current_btns = [self.btn0.is_low(), self.btn1.is_low(), self.btn2.is_low(), self.btn3.is_low()];

        for i in 0..4 {
            // Check button state changes
            if current_btns[i] != self.last_btns[i] {
                self.last_btns[i] = current_btns[i];
                on_event(BoardEvent::EncoderButton { index: i as u8, pressed: current_btns[i] });
            }

            // Check encoder movement
            let diff = current_counts[i].wrapping_sub(self.last_counts[i]) as i16;
            // 4 pulses per detent typical on mechanical encoders
            if diff >= 4 || diff <= -4 {
                let detents = (diff / 4) as i8;
                if detents != 0 {
                    let cw = detents < 0; // Inverted direction
                    let count = detents.abs();
                    for _ in 0..count {
                        on_event(BoardEvent::EncoderTurn { index: i as u8, cw });
                    }
                    self.last_counts[i] = current_counts[i];
                }
            }
        }
    }
}

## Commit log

2026-10-03 pcb: v0.2 with fixes applied
    [bom_main.csv, bom_matrix.csv, bom_peripherals.csv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]
2026-10-07 keycaps: added script to generate laser cutting template
2026-10-07 casing: exported STEP files
    [casing_bottom-left.step, casing_bottom-right.step, casing_bottom.step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]
2026-10-19 led monitoring: increase monitored area to 11x11 pixels per button
2026-11-08 change LED colors
